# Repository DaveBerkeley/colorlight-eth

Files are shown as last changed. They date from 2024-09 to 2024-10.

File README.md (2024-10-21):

ColorLight Ethernet Interface
====

This PCB provides the RJ45 and magnetics to connect a pair of Ethernet sockets to the 
[Colorlight i9](https://github.com/wuxx/Colorlight-FPGA-Projects/blob/master/colorlight_i9_v7.2.md)
FPGA dev board.

I'm using the excellent [LiteX](https://github.com/enjoy-digital/litex) SoC builder from [Enjoy Digital](http://www.enjoy-digital.fr/).

This uses the 
[liteeth](https://github.com/enjoy-digital/liteeth)
library to create the MAC and interface to the PHY.

The dev board contains a pair of Broadcom 
[B50612D](https://github.com/wuxx/Colorlight-FPGA-Projects/blob/master/doc/B50612D-datasheet.pdf)
Gigabit Ethernet Transceivers.

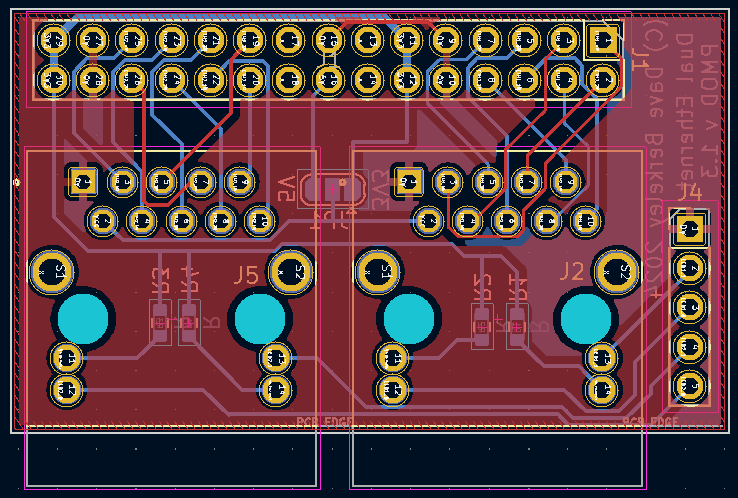
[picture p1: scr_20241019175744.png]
PCB


The project was inspired by this [Ethernet interface](https://github.com/kazkojima/colorlight-i5-tips#ethernet) by kazkojima.

I found an 
[RJ45 connecter](https://www.digikey.co.uk/en/products/detail/trp-connector-b-v/2250013-4/9451594)
with built in magnetics, which makes the whole design a lot simpler.

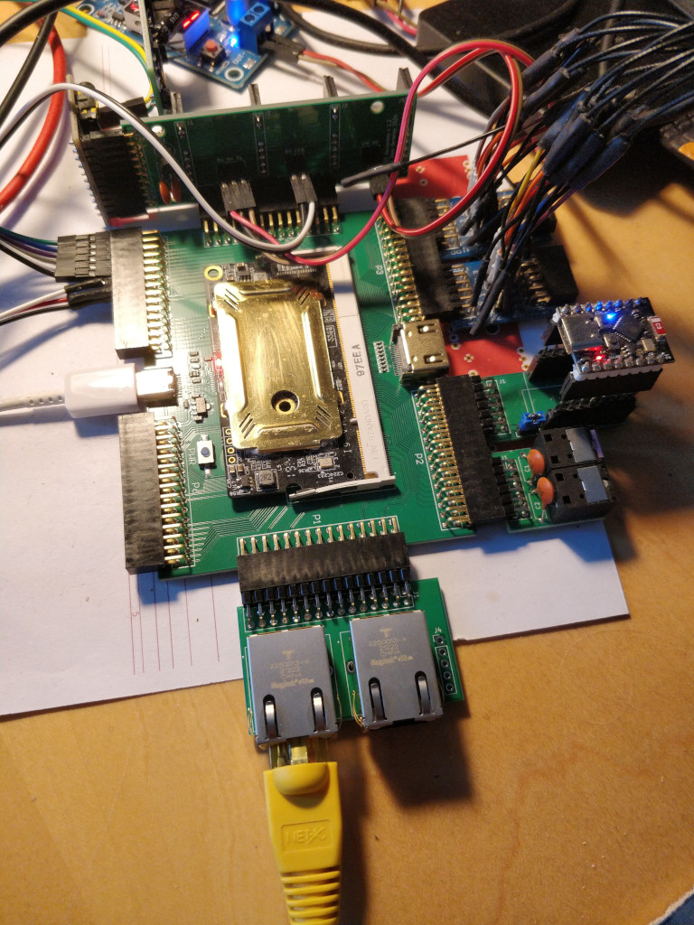
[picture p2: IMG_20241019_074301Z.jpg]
Ethernet Interface attached to the colorlight dev board


I've got the system loading a binary image over TFTP and booting. I've not yet had time to do any more tests.

The edge connector does not have LED outputs on it unfortunately. 
So I've wired these to a 5-pin header on the side of the board.
There are 4 resistors on the back of the board to limit the current through the LEDs.
The LEDs in these sockets are bicolour bidirectional, but only one direction is supported.

There is also a jumper to select between 5V and 3V3 connection to the pulse transformers, 
but the circuit seems to work without this being conencted to either. 
I need to look into its purpose.

I'm currently running [PanglOS](https://github.com/DaveBerkeley/panglos) on the RISC-V.
This doesn't yet have a scheduler on the RISC-V, so I don't have any multitasking.
Software for the Ethernet interface on my board is still work in progess.

            __   _ __      _  __
           / /  (_) /____ | |/_/
          / /__/ / __/ -_)>  <
         /____/_/\__/\__/_/|_|
       Build your hardware, easily!

     (c) Copyright 2012-2024 Enjoy-Digital
     (c) Copyright 2007-2015 M-Labs

     BIOS built on Oct 19 2024 10:06:09
     BIOS CRC passed (bfabfcc0)

     LiteX git sha1: a59b67e4

    --=============== SoC ==================--
    CPU:            VexRiscv_LinuxDebug @ 50MHz
    BUS:            wishbone 32-bit @ 4GiB
    CSR:            32-bit data
    ROM:            128.0KiB
    SRAM:           8.0KiB
    L2:             8.0KiB
    FLASH:          8.0MiB
    SDRAM:          8.0MiB 32-bit @ 50MT/s (CL-2 CWL-2)
    MAIN-RAM:       8.0MiB

    --========== Initialization ============--
    Ethernet init...
    Initializing SDRAM @0x40000000...
    Switching SDRAM to software control.
    Switching SDRAM to hardware control.
    Memtest at 0x40000000 (2.0MiB)...
      Write: 0x40000000-0x40200000 2.0MiB     
       Read: 0x40000000-0x40200000 2.0MiB     
    Memtest OK
    Memspeed at 0x40000000 (Sequential, 2.0MiB)...
      Write speed: 18.4MiB/s
       Read speed: 25.3MiB/s

    Initializing w25q64 SPI Flash @0x00800000...
    SPI Flash clk configured to 25 MHz
    Memspeed at 0x800000 (Sequential, 4.0KiB)...
       Read speed: 2.3MiB/s
    Memspeed at 0x800000 (Random, 4.0KiB)...
       Read speed: 1.0MiB/s

    --============== Boot ==================--
    Booting from serial...
    Press Q or ESC to abort boot completely.
    sL5DdSMmkekro
                 Timeout
    Booting from flash...
    Error: Invalid image length 0xacc0d000
    Booting from network...
    Local IP: 192.168.0.249
    Remote IP: 192.168.0.189
    Booting from boot.json...
    Copying app.bin to 0x40000000... (109760 bytes)
    Executing booted program at 0x40000000

    --============= Liftoff! ===============--
     ____                   _  ___  ____  
    |  _ \ __ _ _ __   __ _| |/ _ \/ ___| 
    | |_) / _` | '_ \ / _` | | | | \___ \ 
    |  __/ (_| | | | | (_| | | |_| |___) |
    |_|   \__,_|_| |_|\__, |_|\___/|____/ 
                      |___/               

    LiteX/PanglOS. Built Oct 19 2024 09:49:13

    1049893 main DEBUG main.cpp +641 app_main() :

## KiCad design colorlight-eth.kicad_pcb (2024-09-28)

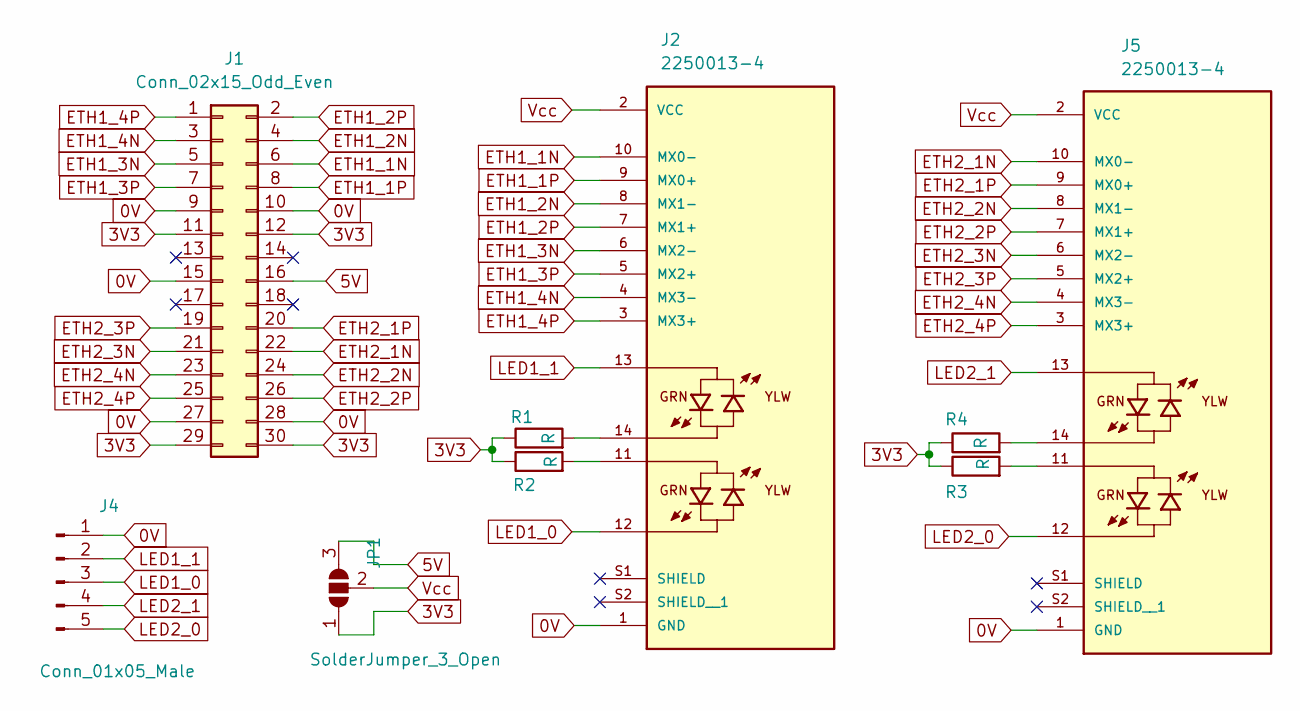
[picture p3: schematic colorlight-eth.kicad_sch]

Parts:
J1: Conn_02x15_Odd_Even; PinHeader_2x15_P2.54mm_Vertical
J2, J5: 2250013-4; BEL_2250013-4; PARTREV 2
J4: Conn_01x05_Male; PinHeader_1x05_P2.54mm_Vertical
JP1: SolderJumper_3_Open; SolderJumper-3_P1.3mm_Open_RoundedPad1.0x1.5mm
R1, R2, R3, R4: R; R_0603_1608Metric

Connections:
0V: J1.9, J1.10, J1.15, J1.27, J1.28, J2.1 (GND), J4.1, J5.1 (GND)
3V3: J1.11, J1.12, J1.29, J1.30, JP1.1 (A), R1.1, R2.1, R3.1, R4.1
5V: J1.16, JP1.3 (B)
ETH1_1N: J1.6, J2.10 (MX0-)
ETH1_1P: J1.8, J2.9 (MX0+)
ETH1_2N: J1.4, J2.8 (MX1-)
ETH1_2P: J1.2, J2.7 (MX1+)
ETH1_3N: J1.5, J2.6 (MX2-)
ETH1_3P: J1.7, J2.5 (MX2+)
ETH1_4N: J1.3, J2.4 (MX3-)
ETH1_4P: J1.1, J2.3 (MX3+)
ETH2_1N: J1.22, J5.10 (MX0-)
ETH2_1P: J1.20, J5.9 (MX0+)
ETH2_2N: J1.24, J5.8 (MX1-)
ETH2_2P: J1.26, J5.7 (MX1+)
ETH2_3N: J1.21, J5.6 (MX2-)
ETH2_3P: J1.19, J5.5 (MX2+)
ETH2_4N: J1.23, J5.4 (MX3-)
ETH2_4P: J1.25, J5.3 (MX3+)
LED1_0: J2.12, J4.3
LED1_1: J2.13, J4.2
LED2_0: J4.5, J5.12
LED2_1: J4.4, J5.13
unnamed: J2.11, R2.2
unnamed: J2.14, R1.2
unnamed: J5.11, R3.2
unnamed: J5.14, R4.2
Vcc: J2.2 (VCC), J5.2 (VCC), JP1.2 (C)

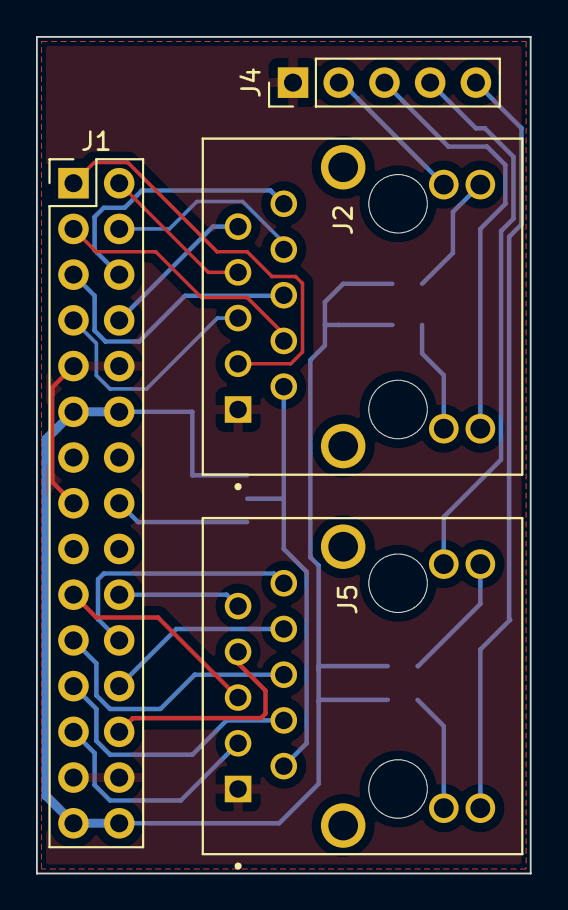
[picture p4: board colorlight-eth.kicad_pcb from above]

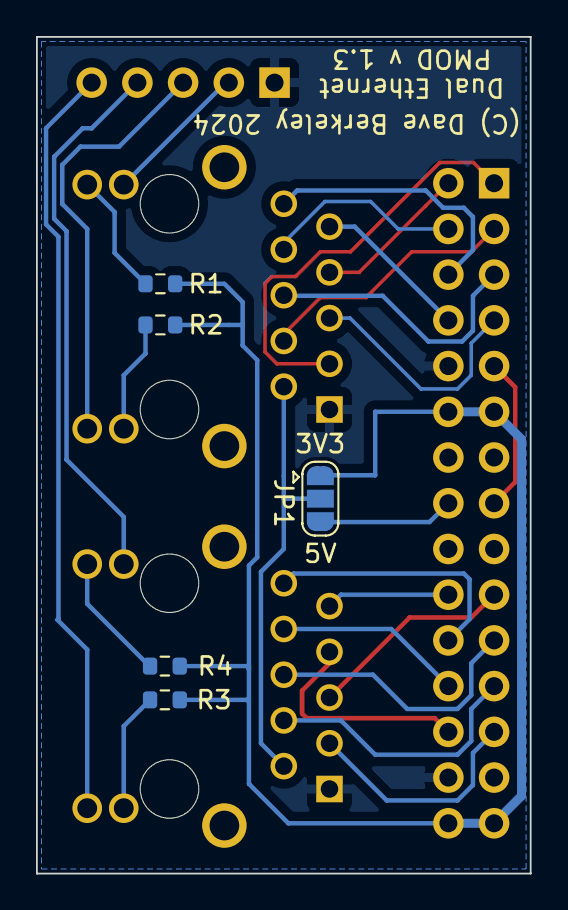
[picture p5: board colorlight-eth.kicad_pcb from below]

Board: 2 copper layers, 27.4 x 46.5 mm, 9 parts (5 on the bottom side), 28 nets.

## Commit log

2024-09-13 v 1.1 : resistors on the back
    [colorlight-eth.kicad_pcb]
2024-09-13 v1.2 : fix 5V feed to magnetics
    [colorlight-eth.kicad_pcb, colorlight-eth.kicad_sch]
2024-09-28 v 1.3 : mirrored connector pins
    [colorlight-eth.kicad_pcb, colorlight-eth.kicad_sch]
2024-10-19 deleted faulty v 1.0 pcb
2024-10-19 Added PCB image
